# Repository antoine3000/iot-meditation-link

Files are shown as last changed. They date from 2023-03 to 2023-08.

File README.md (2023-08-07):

# Meditation Link

Meditation Link invites participants to close their eyes and meditate. This object, equipped with a camera, analyses the participants to detect their level of meditation and communicates from one object to another, inviting others to join a collective meditation.

>  This project is open-source and designed to be built and deconstructed, learned and re-appropriated.

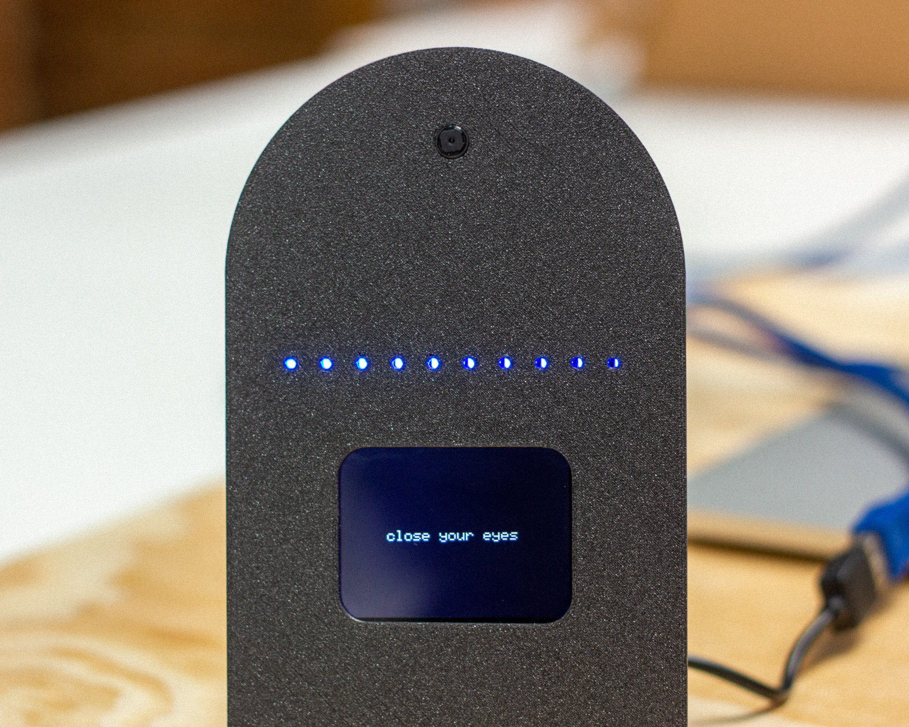
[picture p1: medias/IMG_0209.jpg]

*Meditation Link, a tool for teaching and questioning technology*

## Hardware

### Components

- [Seeed Studio Wio Terminal](https://wiki.seeedstudio.com/Wio-Terminal-Getting-Started/)
- [Grove AI Vision](https://wiki.seeedstudio.com/Grove-Vision-AI-Module/)
- Grove RGB LED Stick
- [3D-printed support](iot-meditation-link-support.stl)

### Assembly instructions

1. 3D print the enclosure
2. Connect the Grove AI vision on the left port of the Wio Terminal
3. Connect the RGB LED Stick on the right port of the Wio Terminal
4. Fit the camera, terminal and LED to the [3D-printed support](iot-meditation-link-support.stl)
5. Power the Wio Terminal with a USB-C cable

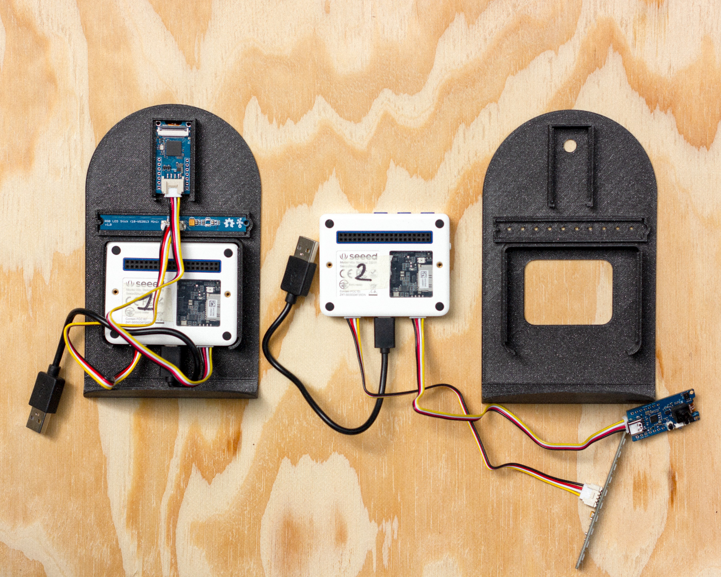
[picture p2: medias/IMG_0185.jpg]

*Assembly, mounted and unmounted*

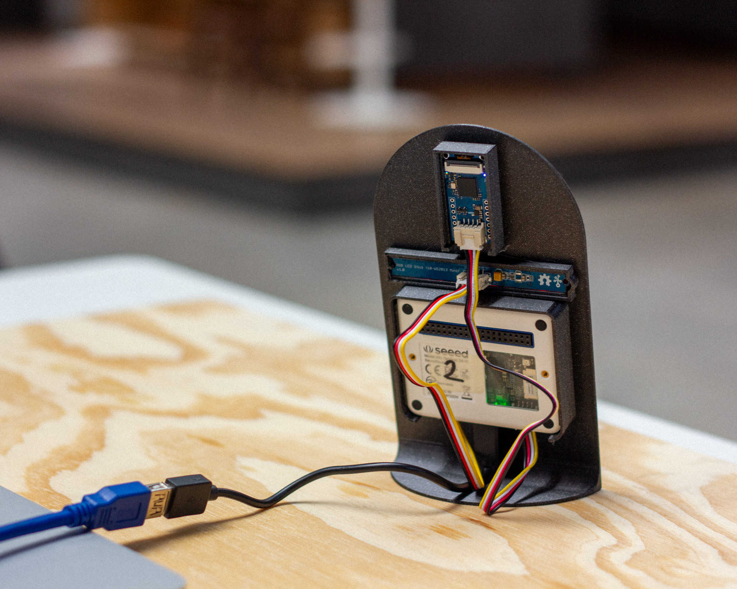
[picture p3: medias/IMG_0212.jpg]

*Assembly, back side*

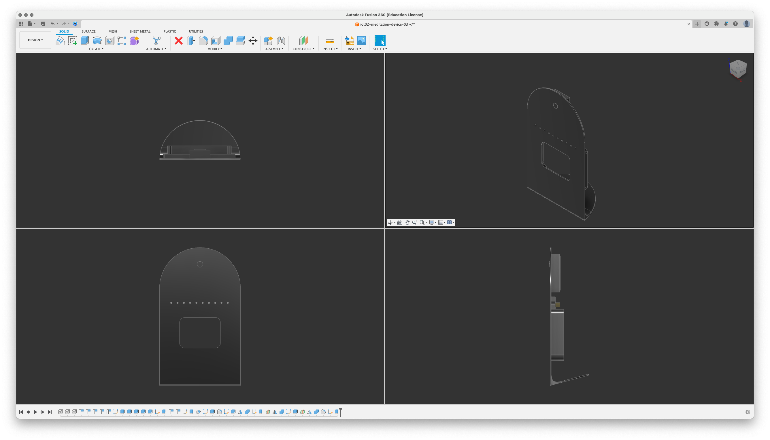
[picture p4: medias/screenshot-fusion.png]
3D design in Fusion 360

*3D design in Fusion 360*

## Software

### AI Camera

#### Resources

1. [Google Collab Sketch](https://colab.research.google.com/gist/lakshanthad/b47a1d1a9b4fac43449948524de7d374/yolov5-training-for-sensecap-a1101.ipynb)
2. [Images dataset](https://universe.roboflow.com/112fkdldjs-gmail-com/eye_open-and-close-test-2/browse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)

#### Method

For the camera to recognise what we want it to recognise, we need to train it with classified images. For this project we chose the image set of open or closed eyes, in order to deduce whether a person is meditating or not.

A relatively complicated code and the installation of a multitude of tools are required to train the AI model. We are not going to do this on our own computer but rather directly on a Google computer in a pre-configured environment. The image set is on Roboflow. We will use this website for our images. Creating an account is necessary.

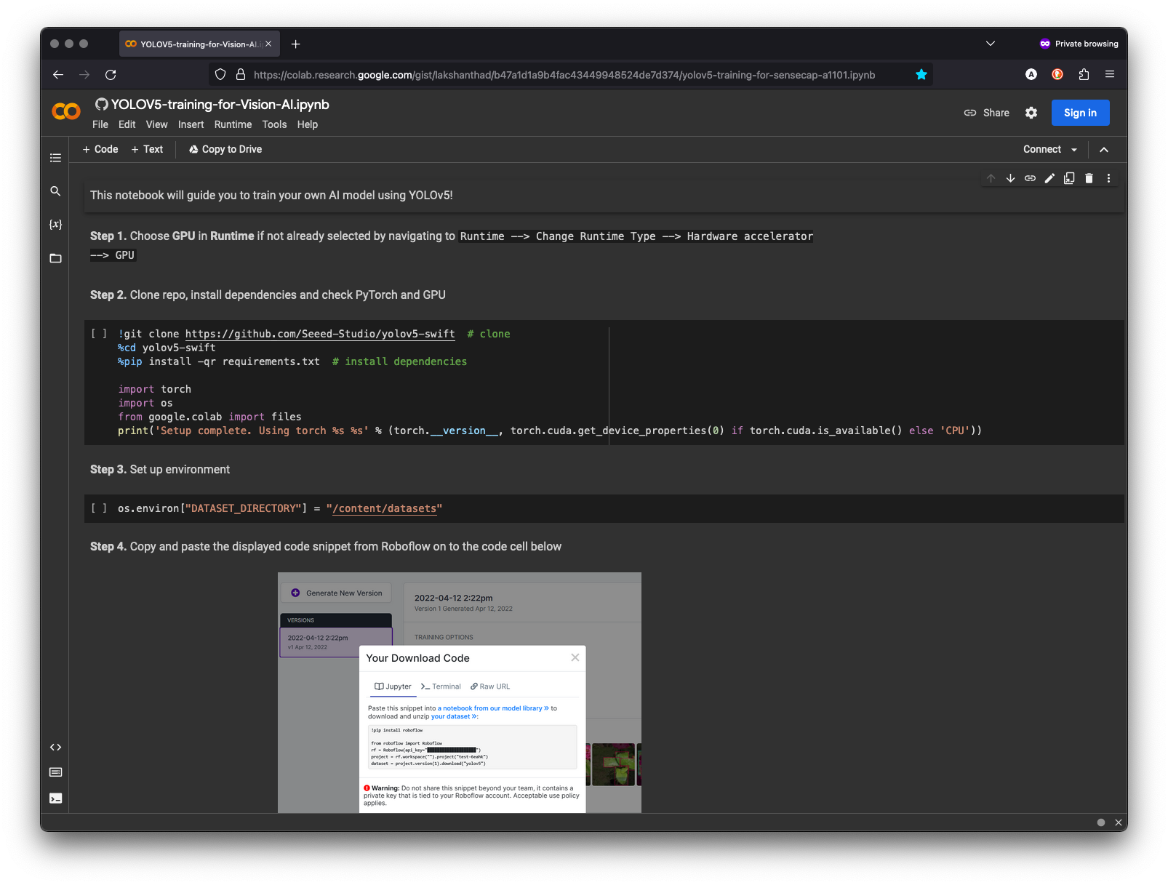
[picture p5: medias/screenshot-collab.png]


- Click on the [ ] at the top right of each block, one by one, to execute the code. Wait for the end of a block before starting the next one.
- For step 4, you will need the download code from the Roboflow dataset page. To get it, click on Export and copy the code.
- The step 6 is the longest, the computer is now learning all it can from the images provided. Be patient.
- When everything is finished, download the UF2 file to your computer.
- Once connected to the USB port of your computer, the camera can be put into bootloader mode by double-clicking the BOOT button.
- A drive will be mounted on your computer with the name GROVEAI. You can drag and drop the previously generated UF2 file into this drive to flash the camera.
- The GROVEAI drive will disappear indicating the firmware has been uploaded.

Find the source: [Generated model](/model-1.uf2)

### Arduino

Arduino allows us to program our board so that it acts as desired. Create a new arduino project and paste the code from iot-meditation-link-arduino.ino into it. It will most likely be necessary to install the few libraries used.

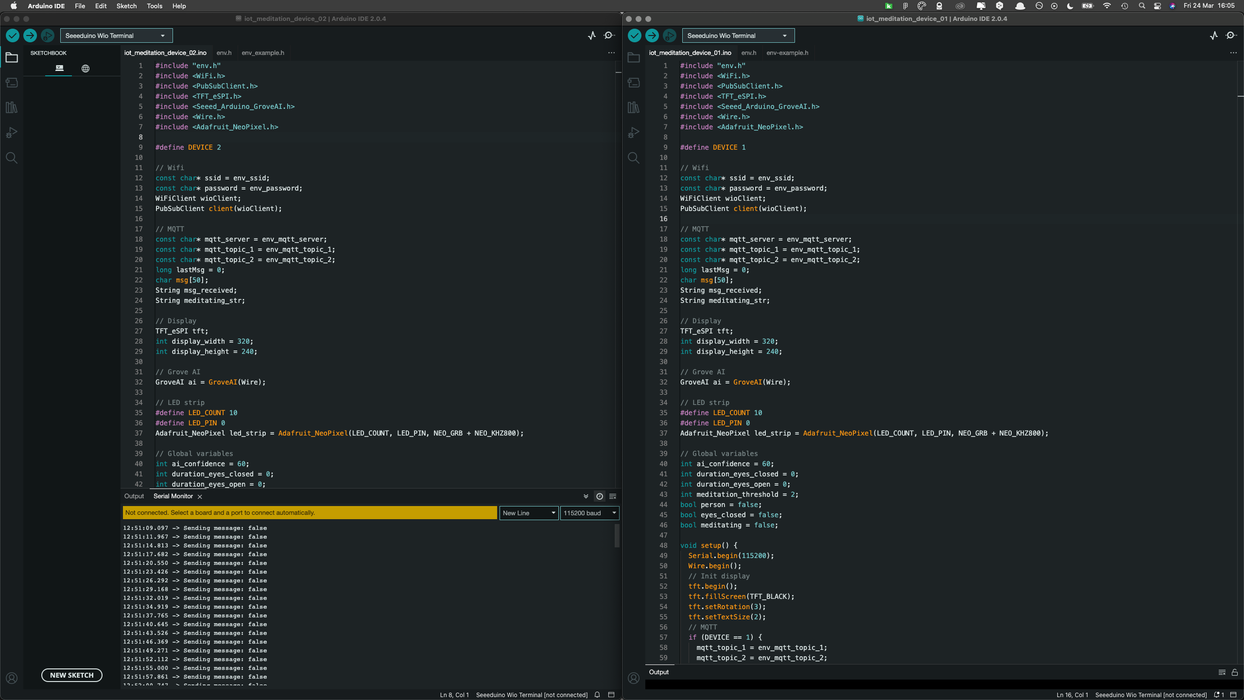
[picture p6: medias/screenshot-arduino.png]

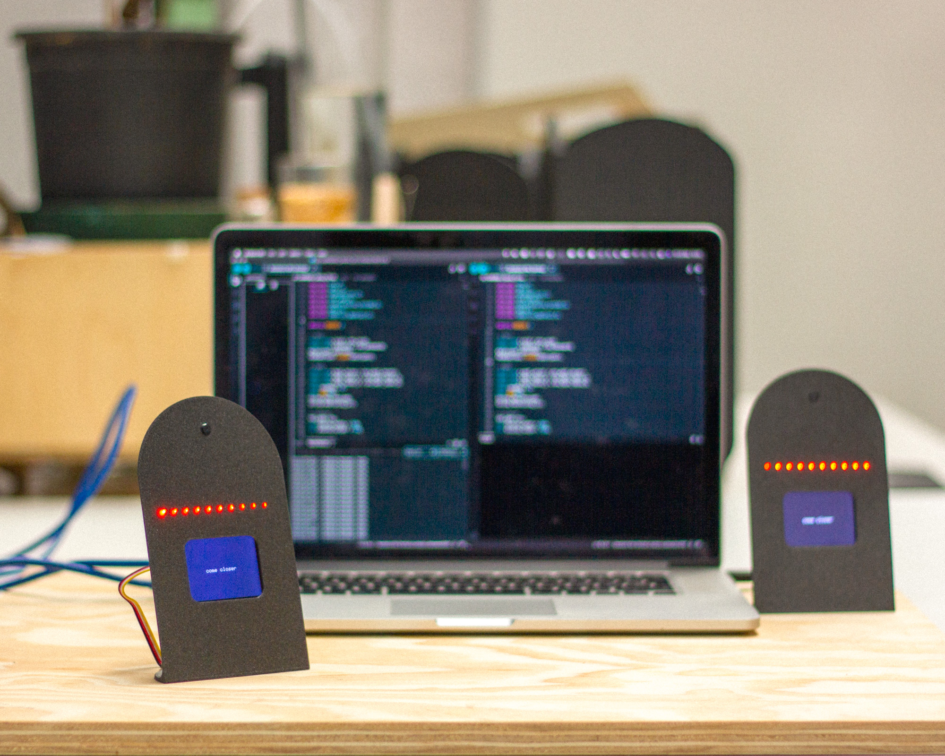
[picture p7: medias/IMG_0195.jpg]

*Complete setup, with both devices*

## Links and references

- [WIO Terminal - Getting Started](https://wiki.seeedstudio.com/Wio-Terminal-Getting-Started/)
- [Get started with WIO Terminal and Wappsto IOT](https://wiki.seeedstudio.com/Get-Started-with-Wio-Terminal-and-Wappsto-IoT/)
- [Train and deploy your own AI model](https://wiki.seeedstudio.com/Train-Deploy-AI-Model/)
- [Arduino Library for Grove Vision AI](https://github.com/Seeed-Studio/Seeed_Arduino_GroveAI)
- [Disk91 - Seeed WioTerminal AI grove camera](https://www.disk91.com/2023/technology/internet-of-things-technology/seeed-wioterminal-ai-grove-camera/)
- [Image dataset](https://universe.roboflow.com/112fkdldjs-gmail-com/eye_open-and-close-test-2/browse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)
- [Google Colab](https://colab.research.google.com/gist/lakshanthad/b47a1d1a9b4fac43449948524de7d374/yolov5-training-for-sensecap-a1101.ipynb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) 
- [simple breathing LED with arduino](https://makersportal.com/blog/2020/3/27/simple-breathing-led-in-arduino)
- [See camera in the browser](https://files.seeedstudio.com/grove_ai_vision/index.html)
- [NeoPixel Library](https://github.com/kitesurfer1404/WS2812FX/blob/master/extras/WS2812FX%20Users%20Guide.md)
- [TFT LCD library](https://wiki.seeedstudio.com/Wio-Terminal-LCD-Overview/#installing-the-tft-lcd-library-separately)
- [MQTT on Wio Terminal](https://www.hackster.io/Salmanfarisvp/mqtt-on-wio-terminal-4ea8f8)
- [Password generator](https://passwordsgenerator.net/)

---

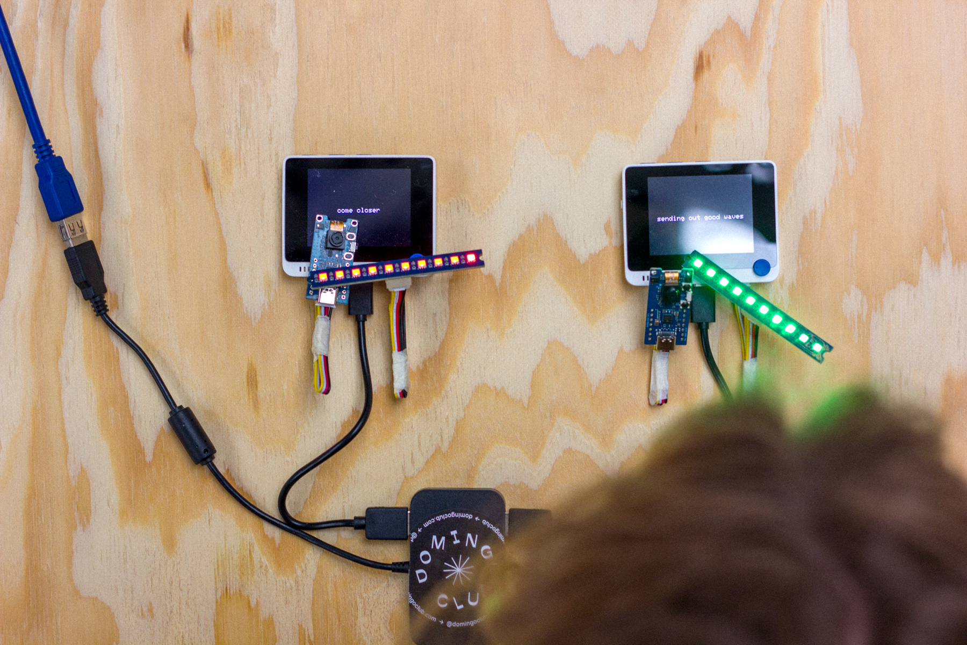
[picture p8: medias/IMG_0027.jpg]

*First prototype*

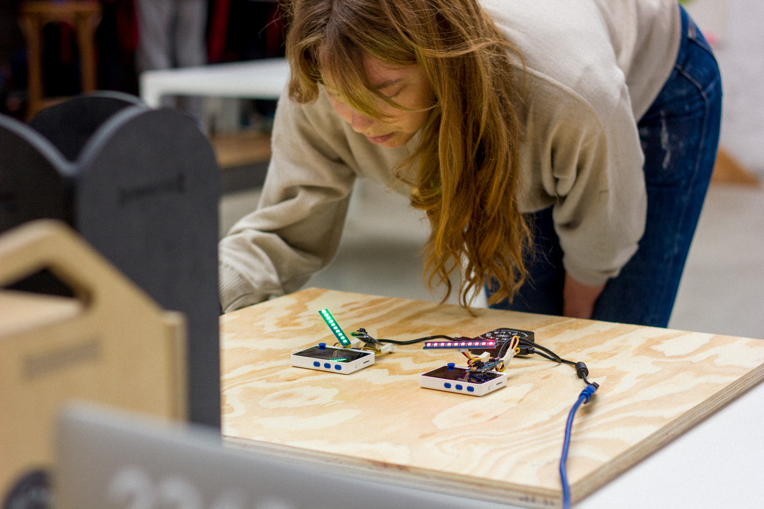
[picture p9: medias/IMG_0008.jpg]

*Testing the device, with closed eyes, not the easiest hehe*

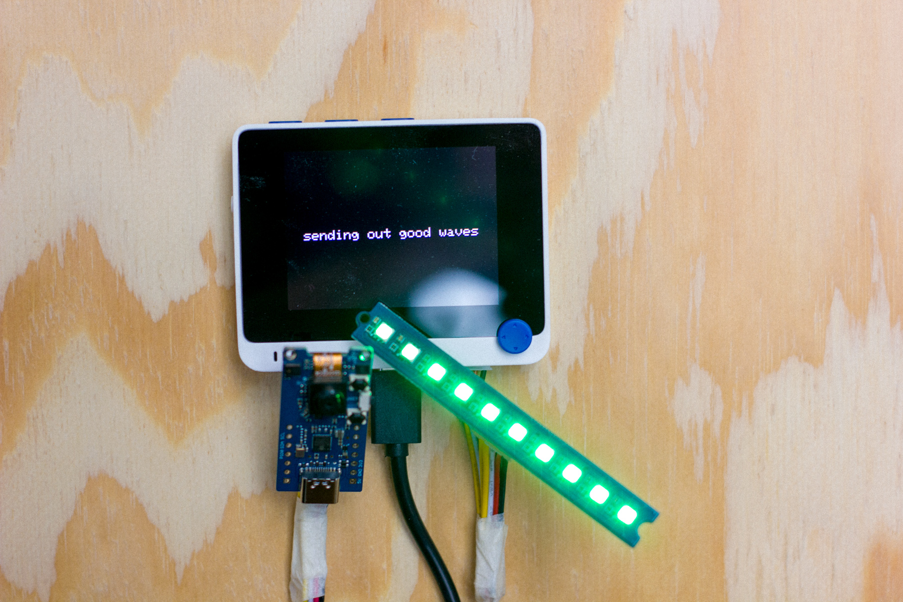
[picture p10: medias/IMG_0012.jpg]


What can technology teach us? What is the scope of objects connected to the Internet? How can they be introduced to the new generations? What are the advantages and disadvantages of such objects? These are the kinds of questions that the European project Internet of Tricks has asked us to consider. We are developing educational kits through which we will run workshops about the place of technology and connected objects in our society.

What is the place of technology in our contemporary lives and what do we want to do with it?

## License

The code is under the [MIT LICENSE](LICENSE), the assets are [BY-NC-SA 4.0](LICENSE.by-nc-sa-4.0.md).

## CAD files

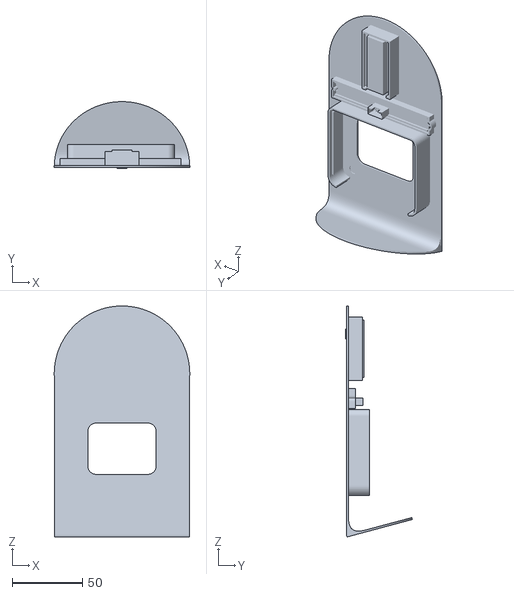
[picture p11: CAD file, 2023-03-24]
iot-meditation-link-support.stl
96.7 x 47.6 x 164.7

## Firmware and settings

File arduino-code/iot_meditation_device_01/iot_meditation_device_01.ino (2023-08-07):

#include "env.h"
#include <WiFi.h>
#include <PubSubClient.h>
#include <TFT_eSPI.h>
#include <Seeed_Arduino_GroveAI.h>
#include <Wire.h>
#include <Adafruit_NeoPixel.h>

#define DEVICE 1

// Wifi
const char* ssid = env_ssid;
const char* password = env_password;
WiFiClient wioClient;
PubSubClient client(wioClient);

// MQTT
const char* mqtt_server = env_mqtt_server;
const char* mqtt_topic_1 = env_mqtt_topic_1;
const char* mqtt_topic_2 = env_mqtt_topic_2;
long lastMsg = 0;
char msg[50];
String msg_received;
String meditating_str;

// Display
TFT_eSPI tft;
int display_width = 320;
int display_height = 240;

// Grove AI
GroveAI ai = GroveAI(Wire);

// LED strip
#define LED_COUNT 10
#define LED_PIN 0
Adafruit_NeoPixel led_strip = Adafruit_NeoPixel(LED_COUNT, LED_PIN, NEO_GRB + NEO_KHZ800);

// Global variables
int ai_confidence = 20;
int duration_eyes_closed = 0;
int duration_eyes_open = 0;
int meditation_threshold = 2;
bool person = false;
bool eyes_closed = false;
bool meditating = false;

void setup() {
  Serial.begin(115200);
  Wire.begin();
  // Init display
  tft.begin();
  tft.fillScreen(TFT_BLACK);
  tft.setRotation(3);
  tft.setTextSize(2);
  // MQTT
  if (DEVICE == 1) {
    mqtt_topic_1 = env_mqtt_topic_1;
    mqtt_topic_2 = env_mqtt_topic_2;
  } else if (DEVICE == 2) {
    mqtt_topic_1 = env_mqtt_topic_2;
    mqtt_topic_2 = env_mqtt_topic_1;
  }
  // Init wifi
  setup_wifi();
  client.setServer(mqtt_server, 1883);
  client.setCallback(callback);
  // Init camera
  if (!ai.begin(ALGO_OBJECT_DETECTION, MODEL_EXT_INDEX_1)) {
    Serial.println("Failed to find camera");
    while (true);
  }
  // Init LED strip
  led_strip.setBrightness(255);
  led_strip.begin();
}

void loop() {
  long now = millis();

  // Make sure you are connected
  if (!client.connected()) {
    reconnect();
  }
  client.loop();

  // Start processing video
  if (ai.invoke()) {
    while (ai.state() != CMD_STATE_IDLE);
    uint8_t len = ai.get_result_len();
    if (len > 0) {
      // some result found
      object_detection_t data;
      // find best accuracy to only display this one
      int high = 0, ihigh = -1;
      for (int i = 0; i < len; i++) {
        ai.get_result(i, (uint8_t*)&data, sizeof(object_detection_t));
        if (data.confidence > high) {
          high = data.confidence;
          ihigh = i;
        }
      }
      ai.get_result(ihigh, (uint8_t*)&data, sizeof(object_detection_t));
      if (data.confidence > ai_confidence) {
        int t = data.target;
        person = true;
        Serial.print("Detected target: ");
        switch (data.target) {
          case 0:
            eyes_closed = true;
            duration_eyes_closed++;
            Serial.print("Eyes closed");
            break;
          case 1:
            eyes_closed = false;
            duration_eyes_open++;
            Serial.print("Eyes open");
            if (duration_eyes_open >= meditation_threshold) {
              duration_eyes_closed = 0;
              duration_eyes_open = 0;
            }
            break;
        }
        Serial.print(" with accuracy ");
        Serial.print(data.confidence);
        Serial.println("%");
      }
    } else {
      person = false;
      duration_eyes_closed = 0;
      duration_eyes_open = 0;
    }
  }

  if (person) {
    if (eyes_closed && duration_eyes_closed >= meditation_threshold) {
      set_led_strip(0, 255, 0, 100);
      tft.fillScreen(TFT_BLACK);
      tft.setCursor((display_width - tft.textWidth("sending out good waves")) / 2, display_height/2);
      tft.print("sending out good waves");
      set_led_strip(0, 50, 0, 100);
      meditating = true;
    } else {
      set_led_strip(0, 0, 255, 100);
      tft.fillScreen(TFT_BLACK);
      tft.setCursor((display_width - tft.textWidth("close your eyes")) / 2, display_height/2);
      tft.print("close your eyes");
      set_led_strip(0, 0, 50, 100);
      meditating = false;
    }
  } else {
    set_led_strip(255, 0, 0, 100);
    tft.fillScreen(TFT_BLACK);
    tft.setCursor((display_width - tft.textWidth("come closer")) / 2, display_height/2);
    tft.print("come closer");
    set_led_strip(50, 0, 0, 100);
    meditating = false;
  }

  if (msg_received == "true") {
    set_led_strip(255, 255, 255, 100);
    tft.fillScreen(TFT_BLACK);
    tft.setCursor((display_width - tft.textWidth("receiving good waves <3")) / 2, display_height/2);
    tft.print("receiving good waves <3");
    set_led_strip(50, 50, 50, 100);
  }


  // Send message every second
  if (now - lastMsg > 1000) {
    lastMsg = now;
    if (meditating) {
      meditating_str = "true";
    } else {
      meditating_str = "false";
    }
    meditating_str.toCharArray(msg, 50);
    client.publish(mqtt_topic_1, msg);
    Serial.print("Sending message: ");
    Serial.println(msg);
  }
}

void setup_wifi() {
  delay(10);
  tft.setCursor((display_width - tft.textWidth("connecting to wifi")) / 2, display_height/2);
  tft.print("connecting to wifi");
  Serial.println();
  Serial.print("Connecting to ");
  Serial.println(ssid);
  WiFi.begin(ssid, password);
  while (WiFi.status() != WL_CONNECTED) {
    delay(500);
    Serial.print(".");
  }
  Serial.println("");
  Serial.println("WiFi connected");
  tft.fillScreen(TFT_BLACK);
  tft.setCursor((display_width - tft.textWidth("connected!")) / 2, display_height/2);
  tft.print("connected!");
  Serial.println("IP address: ");
  Serial.println(WiFi.localIP());  // Display Local IP Address
}

void callback(char* topic, byte* payload, unsigned int length) {
  Serial.print("Message arrived [");
  Serial.print(topic);
  Serial.print("] ");
  char buff_p[length];
  for (int i = 0; i < length; i++) {
    Serial.print((char)payload[i]);
    buff_p[i] = (char)payload[i];
  }
  Serial.println();
  buff_p[length] = '\0';
  msg_received = String(buff_p);
  Serial.print("Receiving message: ");
  Serial.println(msg_received);
}

void reconnect() {
  while (!client.connected()) {
    Serial.print("MQTT connection...");
    tft.fillScreen(TFT_BLACK);
    tft.setCursor((display_width - tft.textWidth("connecting to mqtt")) / 2, display_height/2);
    tft.print("connecting to mqtt");
    String clientId = "WioTerminal-";
    clientId += String(random(0xffff), HEX);
    if (client.connect(clientId.c_str())) {
      Serial.println("connected");
      tft.fillScreen(TFT_BLACK);
      tft.setCursor((display_width - tft.textWidth("Connected!")) / 2, display_height/2);
      tft.print("connected!");
      client.publish(mqtt_topic_1, "hello world");
      client.subscribe(mqtt_topic_2);
    } else {
      Serial.print("failed, rc=");
      Serial.print(client.state());
      Serial.println(" try again in 5 seconds");
      delay(5000);
    }
  }
}

void set_led_strip(int red, int green, int blue, int led_delay) {
  for(int i=0;i<LED_COUNT;i++){
    led_strip.setPixelColor(i, led_strip.Color(red,green,blue));
    led_strip.show();
    delay(led_delay);
  }
}

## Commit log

2023-02-14 arduino code
2023-03-24 doc update with medias
    [iot-meditation-link-support.stl]
